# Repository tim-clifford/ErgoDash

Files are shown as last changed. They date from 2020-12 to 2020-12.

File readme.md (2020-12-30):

# ErgoDash-R

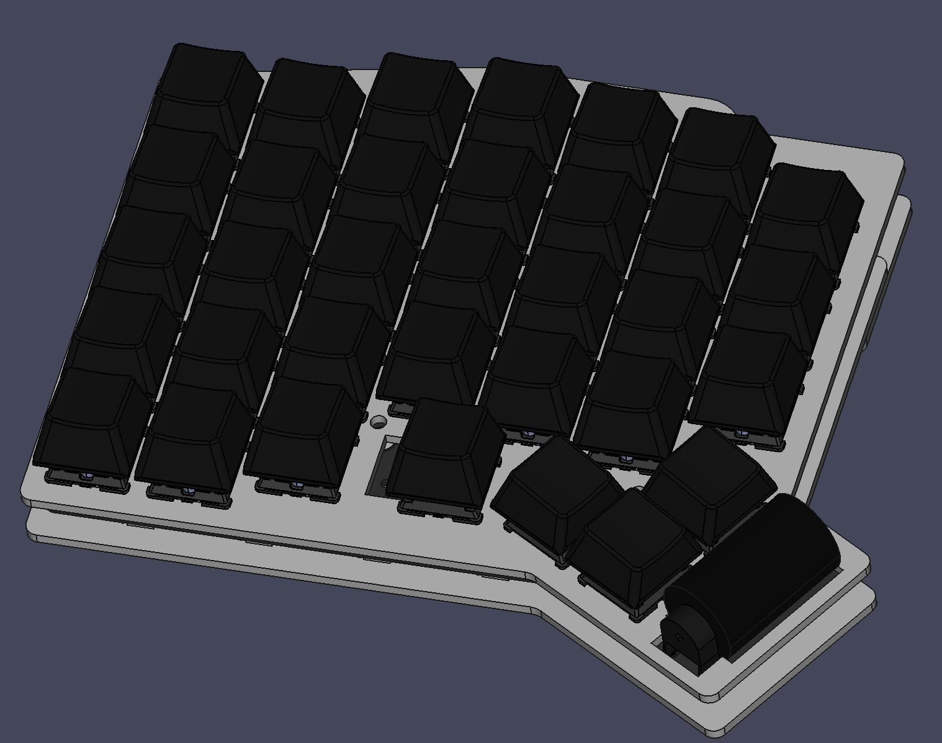
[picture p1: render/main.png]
ErgoDash-R


# Changes from original ErgoDash

- Added rotary encoder (scroll wheel) in place of the ErgoDash's optional outer thumb buttons
- Removed speaker to make pin available for rotary encoder
- Replaced firmware backlight control with physical toggle switch to make pin available for rotary encoder
- Replaced some parts with ones easier to obtain in the UK
- Added jumper pin positions for backlight switch and spare keyboard switch to allow adding functionality later

# Parts

[Parts List](https://github.com/tim-clifford/ErgoDash-R/tree/master/doc/shoplist.ods)

# Firmware

The ErgoDash-R uses QMK for its firmware. It will need updating from the original ErgoDash firmware here:
[QMK - ErgoDash directory](https://github.com/qmk/qmk_firmware/tree/master/keyboards/ergodash)
.  

# Build Guide

I will add a build guide once I have finished building mine! The original ErgoDash build guide is likely to be useful:

[ErgoDash Build Guide](https://github.com/omkbd/ErgoDash/blob/master/Doc/build-en.md)

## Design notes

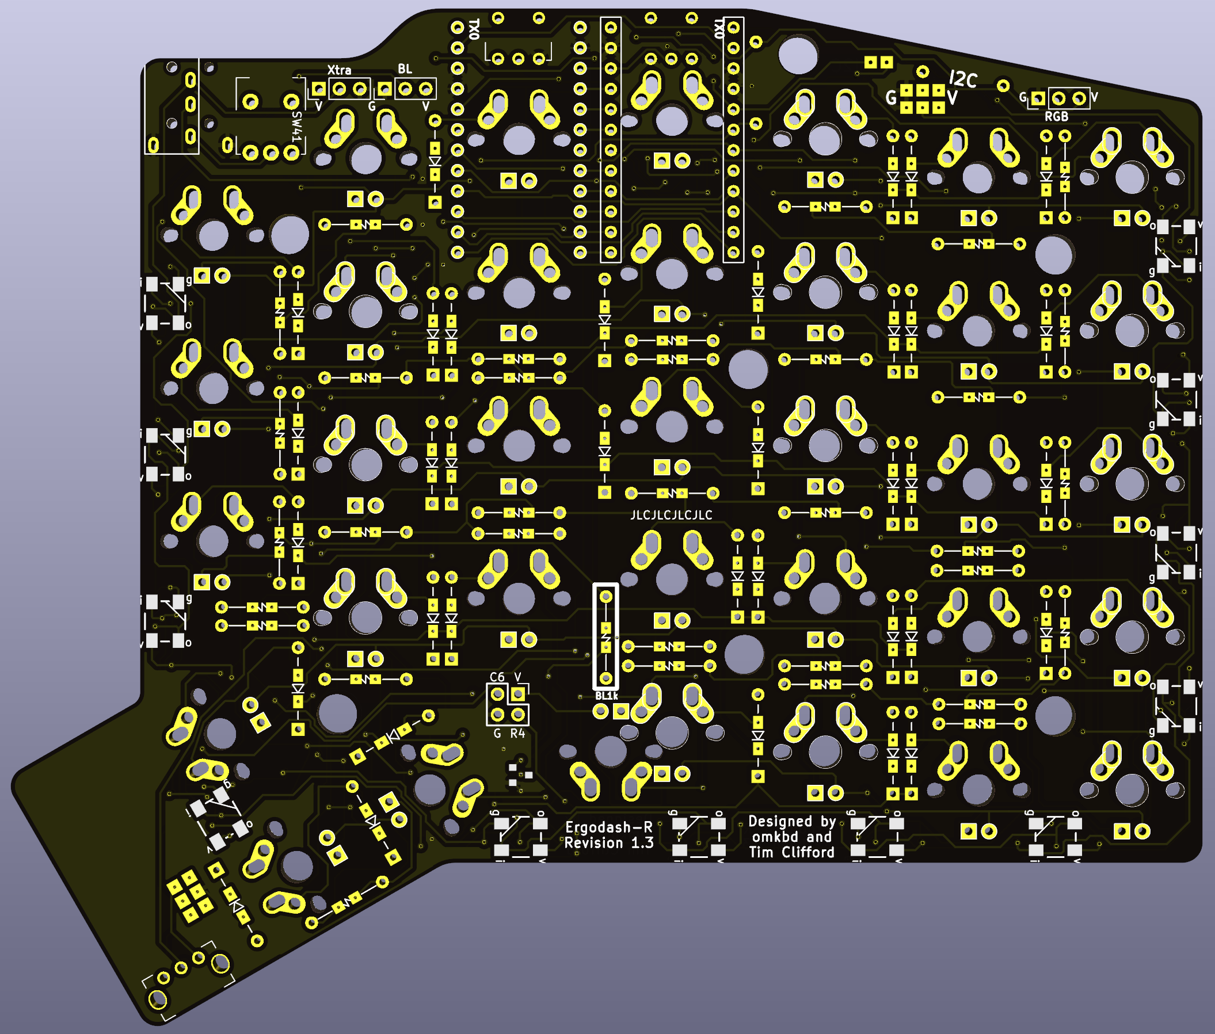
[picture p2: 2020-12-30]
render/pcb-bottom.png

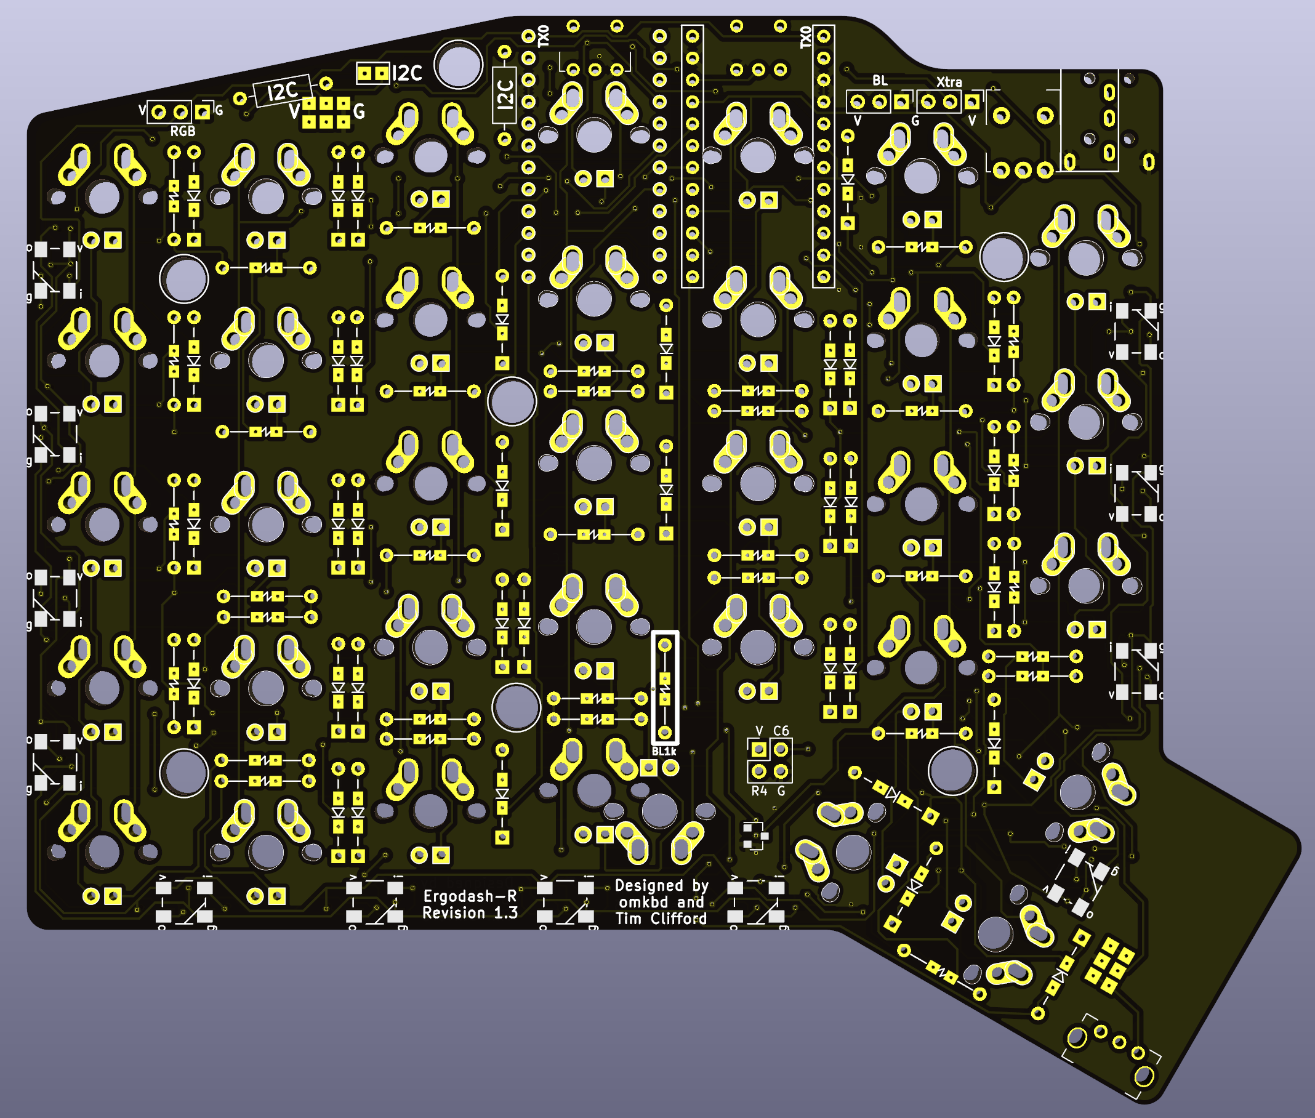
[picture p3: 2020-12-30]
render/pcb-top.png

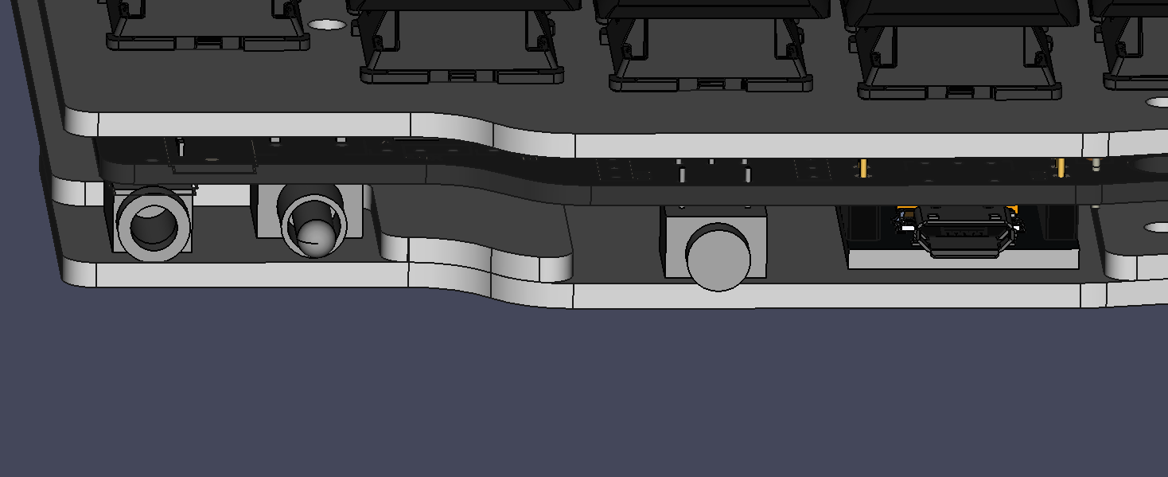
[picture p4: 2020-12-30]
render/io.png

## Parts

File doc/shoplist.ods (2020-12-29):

component | part number | quantity | lead time | pack | price | spares | spares value |  | link
Electronics
PCB | ErgoDash-R Rev 1.3 | 2 | 9-11 business | 5 | £15.74 | 3 | £9.44 | £9.44 | jlpcb.com + gerber files
switches | Cherry MX (Brown) | 68 | 0 | 70 | **£40.00 | 2 |  |  | https://www.ukkeycaps.co.uk/product/cherry-mx-switches
cheap switches | Gateron Blue | 68 | * | 70 | *£21.99 | 2 |  | £0.63 | https://www.ebay.co.uk/itm/70PCS-Pack-3Pin-Gateron-Clicky-Blue-Switch-Keyboard-Switch-for-Mechanical/264980422886
keycaps | Fully custom printed | 68 | * | 105 | **£44.38 | 37 |  |  | https://www.wasdkeyboards.com/104-key-custom-cherry-mx-keycap-set.html
cheap keycaps | QWERTY non backlit | 68 | * | 104 | *£9.90 | 36 |  | £3.43 | https://www.ebay.co.uk/itm/104-OEM-PBT-Double-Shot-Keycaps-Set-Backlit-for-Cherry-MX-Mechanical-Keyboards/203161540282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
diodes | 1N4148 | 70 | 1 | 100 | £1.06 | 30 | £0.32 | £0.32 | https://cpc.farnell.com/unbranded/1n4148/diode-high-speed-do-35-50pk/dp/SC07296
microcontroller | Pro Micro | 2 | 7 | 2 | £11.90 |  |  |  | https://www.ebay.co.uk/itm/Arduino-Pro-Micro-Leonardo-compatible-5V-16MHz-ATmega32U4-headers-UK-TESTED/251960157859
TRRS jack | PJ-320A | 2 | 16-36 | 10 | £2.53 | 8 | £2.02 | £2.02 | https://www.ebay.co.uk/itm/3-5-mm-Audio-Jack-Connector-PCB-Mount-Female-Socket-4-Pin-PJ-320A-10pcs/362585545084
reset switch | P8US8WR2C2M6RES | 2 | 20 | 2 | £3.16
pin header |  | 48 | * | 0
 |  |  |  |  | Total
 |  |  |  | 1st | £34.39 | £66.28 | £11.79 | £15.84
Case |  |  |  | 2nd | £16.12 | £48.01
case |  | 2 | 2 | 2 | £43.14 |  |  |  | razorlab.online + svg files
m2x5 |  | 22
m2x8 |  | 6
m2x6 spacer |  | 14
rubber feet |  | 8
 |  |  |  |  | Total
 |  |  |  | 1st | £43.14 | £43.14 | £0.00 | £0.00
Cables |  |  |  | 2nd | £43.14 | £43.14
TRRS cable |  | 1 | * | 1 | £2.65 |  |  |  | https://www.ebay.co.uk/itm/1m-Slim-4-Pin-3-5mm-Headphone-Aux-Audio-Mic-4-Pole-Stereo-Phone-Cable-1-metre/362051814231
micro-usb cable |  | 1 | * | 1 | £3.00
 |  |  |  |  | Total
 |  |  |  | 1st | £5.65 | £5.65 | £0.00 | £0.00
Scroll |  |  |  | 2nd | £5.65 | £5.65
rotary encoder | (Kailh Red) 9mm | 2 | 30-50 | 5 | £2.61 | 3 | £1.57 | £1.57 | https://www.ebay.co.uk/itm/5Pcs-Kailh-Edition-Mouse-Encoder-Highly-Accurate-Mouse-Decoder-Red-Core/293063741060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
knob | 28x17mm LxD | 2 | 3 | 2 | £12.78 |  |  |  | https://ironmongeryexperts.co.uk/matt-black-17mm-dia-knurled-cupboard-knob.html
grub screw | M4 – 2mm allen | 2 |  | 5 | £2.99 | 3 | £1.79 | £1.79 | https://www.ebay.co.uk/itm/M2-M2-5-M3-M4-M5-ALLEN-KEY-GRUB-SCREWS-CUP-POINT-SCREWS-A2-STAINLESS-DIN-916/383694660868
shaft | 1.74mm – 2mm allen | 2 | * | 0
 |  |  |  |  | Total
 |  |  |  | 1st | £18.38 | £18.38 | £3.36 | £3.36
Backlight |  |  |  | 2nd | £12.78 | £12.78
LEDs | 3mm purple | 68 | 5 | 100 | £4.95 | 32 | £1.58 | £1.58 | https://www.ebay.co.uk/itm/3mm-5mm-10mm-Ultra-Bright-Round-Water-Clear-LED-Bulb-3V-Light-Emitting-Diode/391733543929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
LED resistors | 470 maybe | 68 | 7 | 100 | £1.50 | 32 | £0.48 | £0.48 | https://www.ebay.co.uk/itm/272109823572?var=570918702940
signal resistors | 1k | 2 | 1 | 10 | £0.36 | 8 | £0.29 | £0.29 | https://cpc.farnell.com/multicomp-pro/mcmf006ff1001a50/res-1k-1-600mw-axial-metal-film/dp/RE07777
MOSFETs | IRLML6344TRPBF | 2 | 13 | 8 | £4.01 | 6 | £3.01 | £3.01 | https://www.ebay.co.uk/itm/193406202200
switch | MC2MS1T2B2M6RE | 2 | 1 | 2 | £2.26 |  |  |  | https://cpc.farnell.com/multicomp/mc2ms1t2b2m6re/switch-pcb-spdt-horiz/dp/SW02456?ost=mc2ms1t2b2m6re
 |  |  |  |  | Total
 |  |  |  |  | £13.08 | £13.08 | £5.36 | £5.36
Underglow |  |  |  |  | £8.71 | £8.71
LEDs or LED tape | WS2812B | 24 |  | 100 | £24.86 | 76 | £18.89 | £18.89 | https://www.amazon.co.uk/WS2812B-LED-5050-Controller-WS2811/dp/B00KFOLQ5O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
 |  |  |  |  | Total
 |  |  |  |  | £24.86 | £24.86 | £18.89 | £18.89
 |  |  |  |  | £0.00 | £0.00
CPC delivery total |  |  |  |  | £5.99 | £5.99
 |  | Core electronics |  |  | +Scroll wheels |  | +Per-key backlight |  | +Case |  | +RGB underglow & cables
 | 1st | £34.39 |  | £66.28 | £52.77 | £84.66 | £65.85 | £97.74 | £108.99 | £140.88 | £145.49 | £177.38
 | 2nd | £16.12 |  | £48.01 | £28.90 | £60.79 | £37.61 | £69.50 | £80.75 | £112.64 | £92.39 | £124.28
 |  | With no keyswitches or keycaps
 |  | With Gateron blues and stock ANSI keycaps

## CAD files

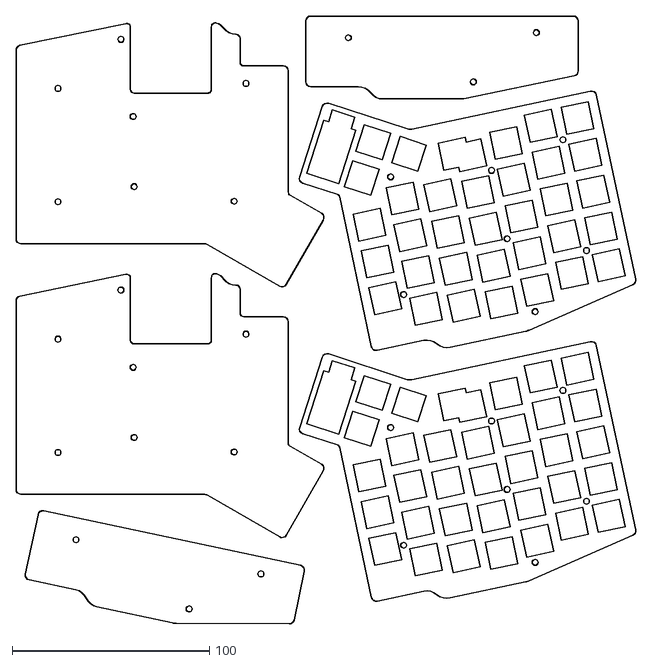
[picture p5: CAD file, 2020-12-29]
case/ErgoDash_Case.dxf
314.1 x 308.0

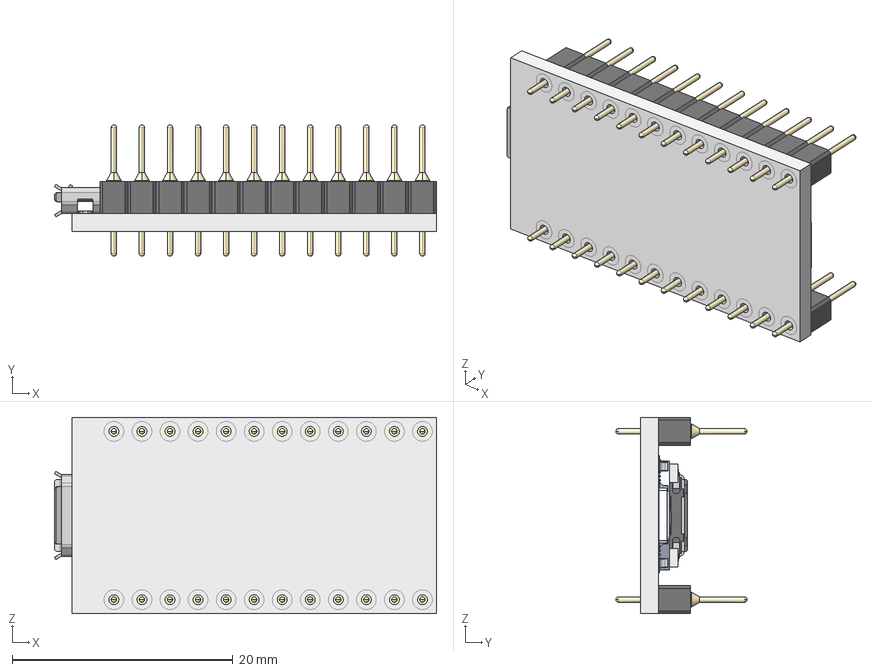
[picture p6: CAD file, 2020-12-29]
MCAD/parts-fcstd/ProMicro16MHz.FCStd
34.6 x 11.9 x 17.8 mm
MICRO_stackable header 12 x 2
MICRO_stackable header pin x 24
micro usb shell
micro usb internal
micro usb contact x 5
atmega32U4
MICRO_cap106C x 2
micro_crystal 5x3
micro_MIC5219
MICRO_PTC-1206
MICRO_603 cap on pad x 7
SOD 323
micro board

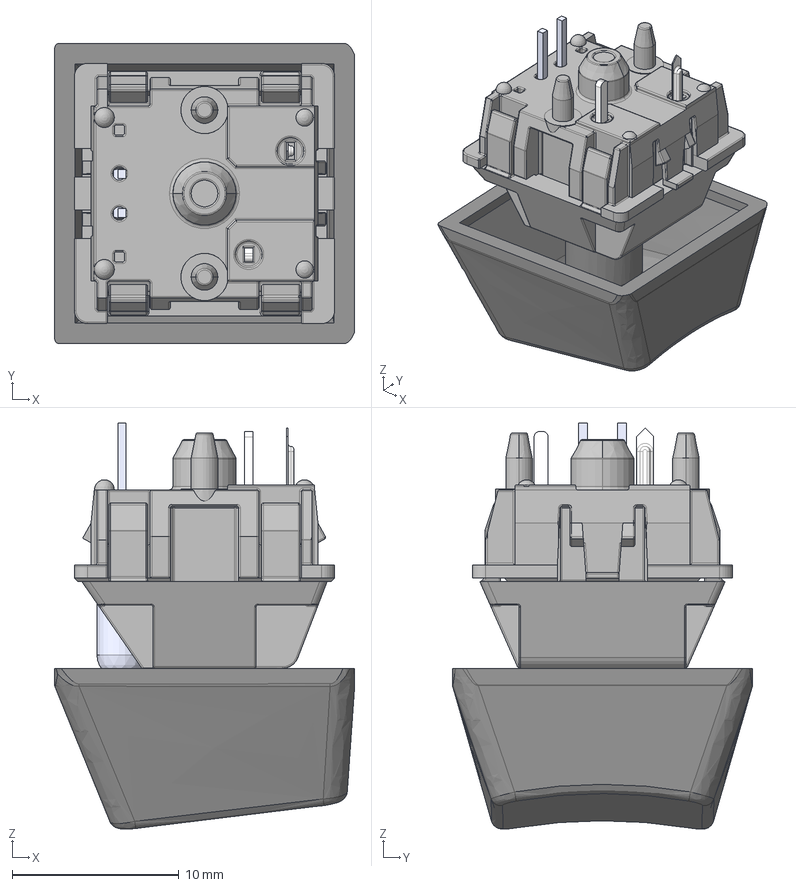
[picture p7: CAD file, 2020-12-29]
MCAD/parts-step/Cherry_MX_Switch_and_Keycap.step
18.0 x 18.0 x 24.3 mm
MX_轴_按键′_ü___¨1 x 2
MX_?_??ｨ｢ｨｬ_｡ｧ｡?__ x 2
MX?_?EDLEDLED x 2
MXﾖ畧ﾖ睥蘋ｵﾗｲｿ_ｦﾌ｡ﾁ2__ﾄｬﾈﾏ_ｨ｢2____ｨｨ_ x 2
?ｽ?__??__ｨｨ_ x 2
Cherry_MX_Keycap x 2

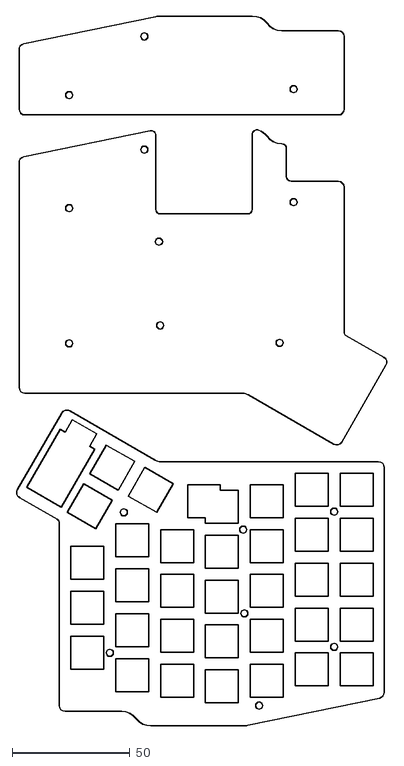
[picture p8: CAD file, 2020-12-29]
case/ErgoDash_Case_Half.dxf
157.5 x 301.4

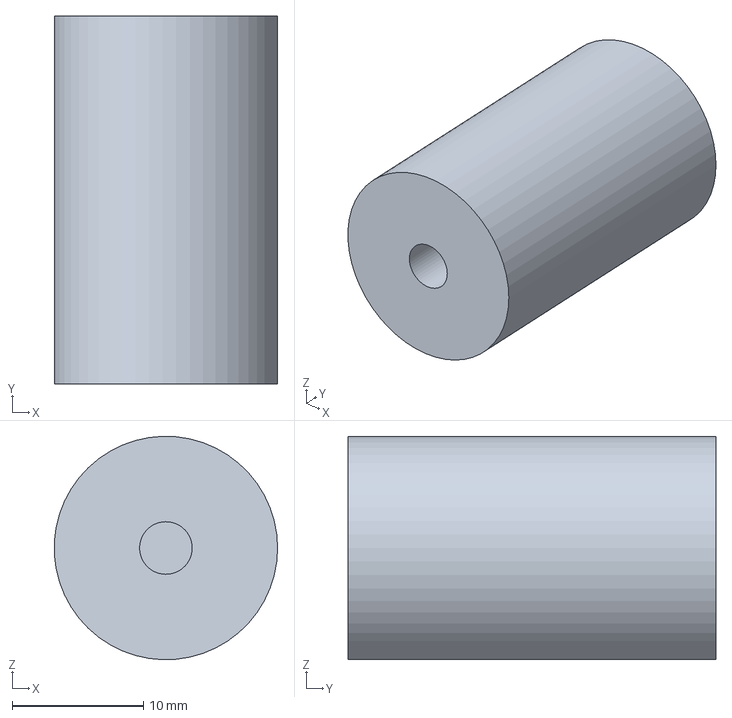
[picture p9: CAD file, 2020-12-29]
MCAD/parts-fcstd/Encoder_Knob.FCStd
17.0 x 28.0 x 17.0 mm

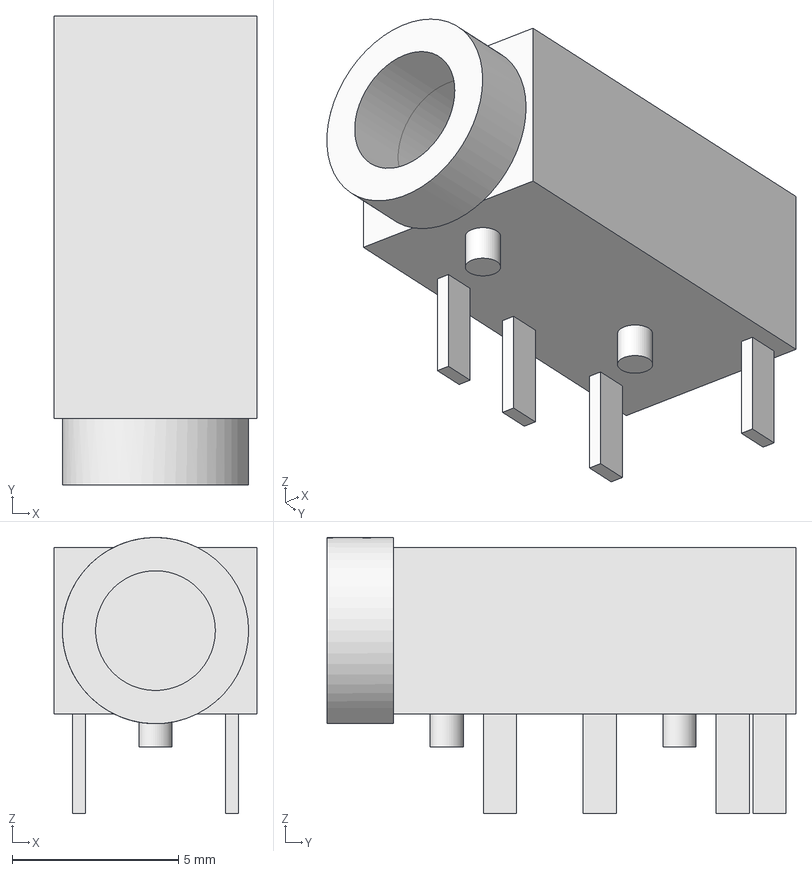
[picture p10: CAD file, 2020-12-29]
MCAD/parts-step/PJ320A_trrs_jack.step
6.10 x 14.1 x 8.30 mm

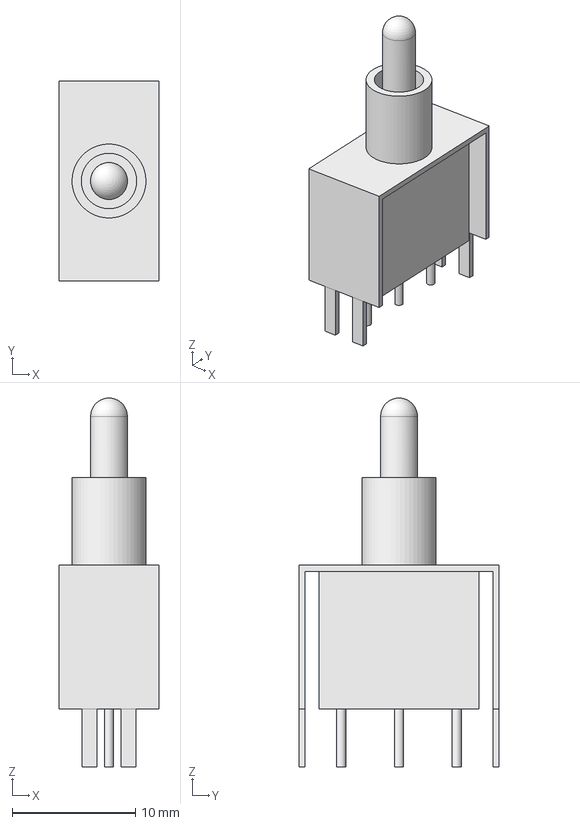
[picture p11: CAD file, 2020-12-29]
MCAD/parts-step/1MS1T2B4VS2RES_SPDT_Toggle_Switch.step
8.13 x 16.3 x 30.0 mm

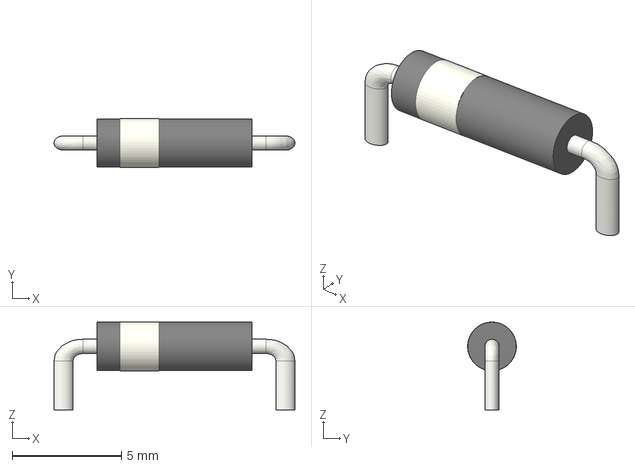
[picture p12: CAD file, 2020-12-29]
MCAD/parts-step/1N4148.step
11.0 x 2.23 x 4.03 mm

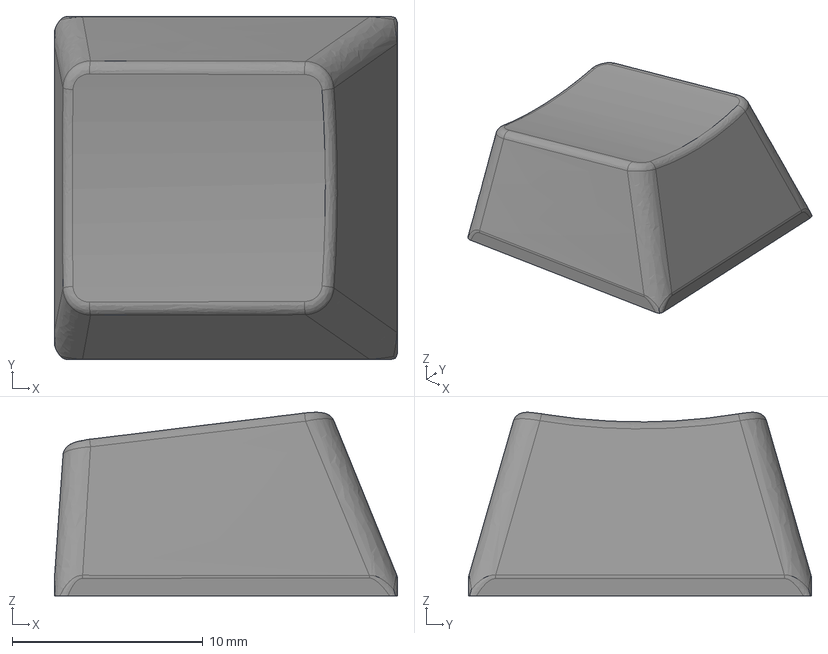
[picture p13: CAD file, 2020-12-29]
MCAD/parts-step/Cherry_MX_Keycap.step
18.0 x 18.0 x 9.64 mm

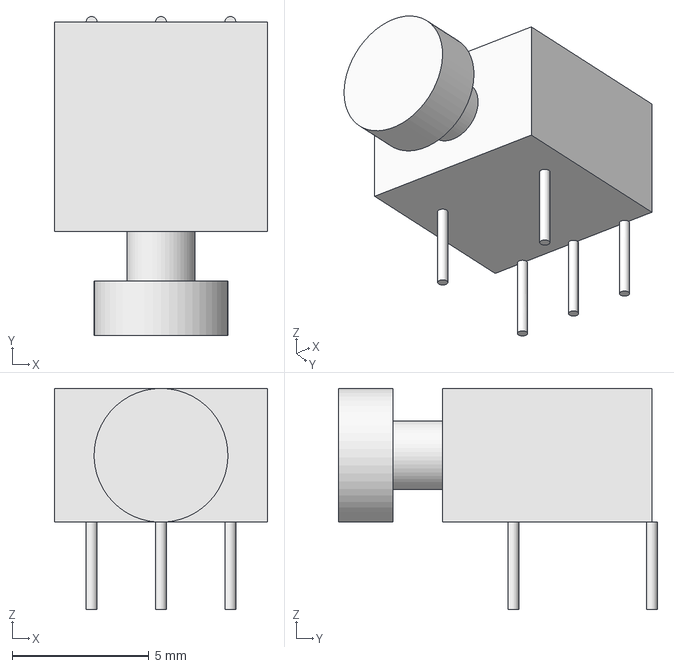
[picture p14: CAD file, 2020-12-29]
MCAD/parts-step/P8US8WR2C2M6RES_Push_Button.step
7.80 x 11.7 x 8.10 mm

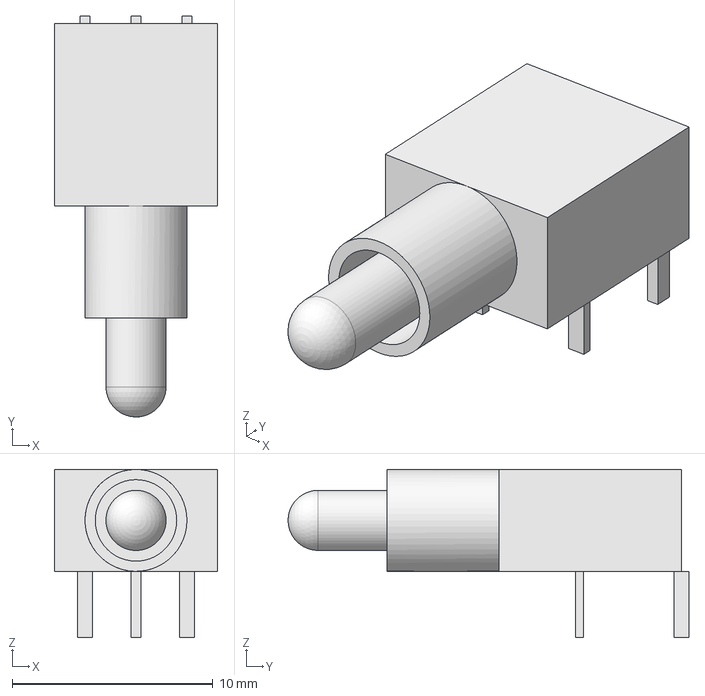
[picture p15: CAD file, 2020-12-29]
MCAD/parts-step/MC2MS1T2B2M6RE_SPDT_Toggle_Switch_Horizontal.step
8.13 x 20.0 x 8.38 mm

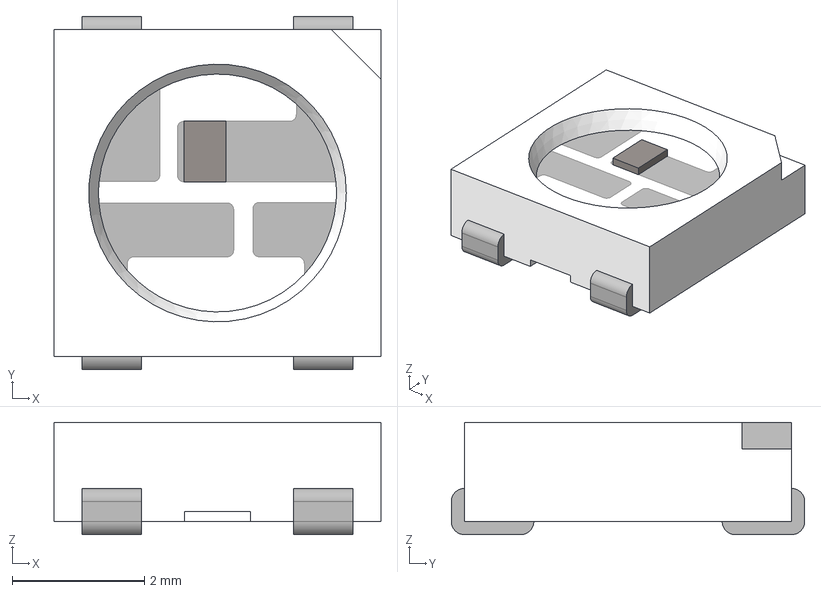
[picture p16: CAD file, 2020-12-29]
MCAD/parts-step/WS2812_RGB_LED.step
4.95 x 5.35 x 1.70 mm

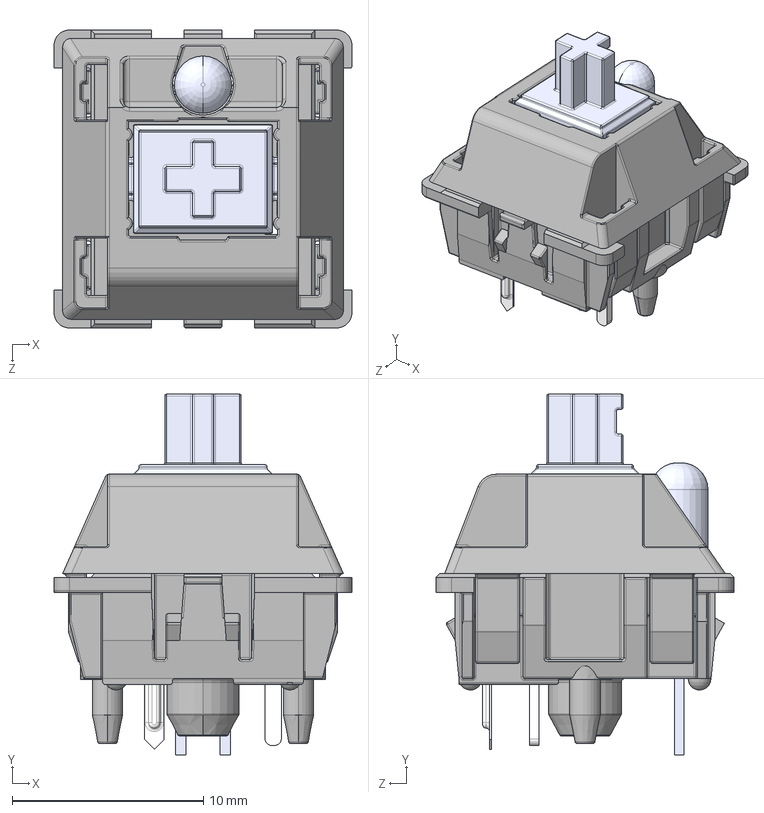
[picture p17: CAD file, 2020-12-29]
MCAD/parts-step/Cherry_MX_Switch.step
15.6 x 18.9 x 15.6 mm
MX 轴 按键′_ü___¨1
MX 轴 轴体áì_¨￠¨__
MX粣 拸簽LEDLEDLED
MX轴 轴体 底部 μ×2__默认_á2____è_
针脚___默认__è_

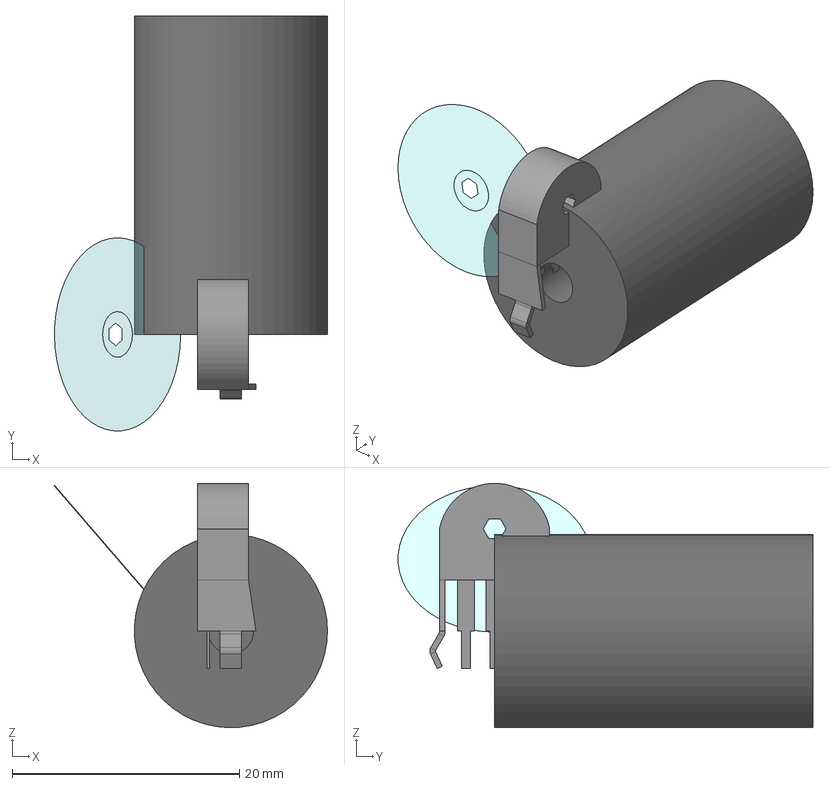
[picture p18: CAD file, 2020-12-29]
MCAD/parts-fcstd/CEN979012RO2_Kailh_Red_Encoder_9mm_with_Knob.FCStd
24.0 x 36.5 x 21.5 mm
CEN979012RO2_Kailh_Red_Encoder_9mm
Knob
_Element
_Element001

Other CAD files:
MCAD/parts-step/Cherry_MX_Switch_and_Keycap180.step
MCAD/parts-step/CEN979012RO2_Kailh_Red_Encoder_9mm.step
MCAD/ergodash-B_Silkscreen.dxf
MCAD/ergodash-F_Silkscreen.dxf
MCAD/parts-fcstd/1MS1T2B4VS2RES_SPDT_Toggle_Switch.FCStd
MCAD/parts-fcstd/CEN979012RO2_Kailh_Red_Encoder_9mm.FCStd
MCAD/parts-fcstd/Cherry_MX_Switch_and_Keycap.FCStd
MCAD/parts-fcstd/Cherry_MX_Switch_and_Keycap180.FCStd
MCAD/parts-fcstd/MC2MS1T2B2M6RE_SPDT_Toggle_Switch_Horizontal.FCStd
MCAD/parts-fcstd/P8US8WR2C2M6RES_Push_Button.FCStd
MCAD/parts-fcstd/PJ320A_trrs_jack.FCStd

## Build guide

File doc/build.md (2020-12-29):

# Notice

This is the build guide for the original ErgoDash, there are some differences for the ErgoDash-R! I will get around to rewriting this eventually.

# ErgoDash Build Guide
**Feel free not to read completely, but pay attention when installing the Pro Micro!!!!!!**
Note: The below diagrams are for rev 1.1. For rev 1.2. and up, the part placement is slightly different.

Translated, with extra build notes (From: build.md https://github.com/omkbd/ErgoDash/commit/d12e8f7fd414fe89d38b77b3b0e6a0af4b639a47)

## Overview
assembly

## 0 Preparation
Remove extra thumb key section if desired.
PCBcut
carefully break by hand

**Note:
Components in steps 3-6 and 10 must be inserted on the bottom of the board.
Components in steps 1 and 2 can be installed on the top or bottom.**

## 1 Install Diodes
When installing diodes the black stripe is towards the square pad
(diodes are all 1 square 1 round pad)
(resistors are all both round pad)
diode

Note the positions of diodes and resistors to avoid mistakes
diode

**Rev 1.2 positions are changed as below.**
diode

## 2 Backlight LED [optional]
Install the MOSFET (Install note/suggestion: pre-soldering the single pad worked well)
Install 1kΩ resistor in silk rectangle as noted 。(Silk screen notation is improved on rev 1.2 [BL1k])
1k

Install 470Ω resistors


-Note: Photo has a few surface mount resistors combined with through-hole
**(Rev 1.1) For the resistor found under the pro-micro: a surface mount resistor, or installing resistor on opposite side may be preferred to prevent interference (moved in rev 1.2)**

## 3 TRRS Jack
On the underside of the board, install the TRRS Jack as indicated by the silkscreen.

## 4 Install reset switch
The reset switch needs to go the underside of the board.
At the top of the board there are 2 locations for the pro-micro.
Pro Micro will be installed where the rectangular outline is printed
Reset switch is installed where the rectangular outline is not seen
Compare with photo on Step 6

## 5 Underglow LED [optional]
**The latest firmware is as follows.**  
There is no need to decide on a master.  
Jump from the back as follows.  
jump2  
Attach the LED chip so that the cut on both sides matches the silk.

**The firmware before 2019/5/5 is implemented as follows.**  
~~Choose which of the pair (left or right) will be master (where the USB cable will be attached), and solder the jumpers as below.~~  
~~The board in the photo below has the jumpers soldered for left hand master. The left hand board is on the right, and the right hand board is on the left.~~  
~~In the two diagrams, the upper image is for left hand master (labelled 左マスター), and the lower image is for right hand master (右マスター).~~  
jump

~~Install LED WS2812B~~  
~~**IMPORTANT**~~  
~~-On Master half, LED corner will Match the silkscreen~~  
~~-On Slave half, LED corner needs to be 180 from silkscreen~~  

-Installation notes:
  -use tape to hold in place, solder one side, remove tape, then solder other
  -Notes from first time soldering with these LED:
    -I attempted to pre-solder pads with bad results (As recommended for other surface mount I did before)
    -Leaving iron on too long appeared to melt the casing of the LED (Use fine tip if you have it? I didnt)
    -1sec on pad to pre-heat, then off and come back with iron and solder is what worked best for me

RGB_Left
RGB_Left_Finish

## 6 Pro Micro header  and reset switch installation
On the underside, attach Headers where you see the rectangular outline on silkscrean  (It is in the correct position on each side of the board)
**Do Not attach Pro Micro Yet**
When using spring headers, soldering the header to the board is unnecessary.

pin

## 7 Install Stabilizer （rev 1.2 or Later only）[optional]

(I used Rev 1.1 without Stabilizers, translation below)

If you will be using 2U keycap(s), then attach the stablizer(s). (If necessary; it's not always required).
**Note: Once the switch is installed, it's no longer possible to attach the stabilizer.**
Put together and attach as shown below.
assembly
If you're concerned about the noise of the stabilizer then apply grease (not included in kit).

## 8 Install Switches and Plate
Make sure all other components are installed before adding switches.
Place the plate with keyholes over top the PCB and snap in and solder switches.
Start with 4 corners in the plate to ensure alignment.
After the first 4 are soldered in, install remaining switches.
Just above the "ergoDash Rev 1.2" sign, there is two possible locations for the switch.
The recommanded location is at the right side for the right part of the keybord (to use it as arrow keys).
And at the left side for the left part of the keyboard (as a modifier)
See this picture (https://raw.githubusercontent.com/omkbd/picture/master/Ergodash.jpg)

switch
switch_complete

## 9 Backlight LED Install [optional]
Install the LEDs from the top on each switch
Round Pad  anode（＋）(Long LED Leg)
Square Pad  cathode（-) (Short Leg)
-Can be installed later (Except for the LED under pro-micro)

## 10 Pro Micro Install
**Before proceding connect the Pro Micro to a PC via USB and confirm it's working.**
-Confirm the TX0 lines up (USB port sandwiched between both PCBs)
-Check that all solder connections underneath the Pro Micro are done.
-Confirm no contact between Pro Micro and components (add insulating tape if desired)
-For spring headers, solder is required on the Pro Micro side.
-After installation, confirm the Pro Micro is properly seated. If not, cut the legs of the switch under the Pro Micro slightly.
-Trim headers after testing.

## 11 Case Assembly
Install the 5mm screws and 6mm spacers from the top。

spacer

Install 5mm and 8mm screws according to the diagram。

case

Install Rubber feet

gom

## 12 Firmware

QMK Build Guide
https://docs.qmk.fm/#/getting_started_build_tools

ErgoDash Firmware
https://github.com/qmk/qmk_firmware/tree/master/keyboards/ergodash

If the right hand side is the master, you need to build the firmware by specifying `MASTER_RIGHT` in the config.h file in the key map of qmk.  
To turn on Backlight and Underglow, add the following to rules.mk in the keymap.  
`BACKLIGHT_ENABLE = yes`  
`RGBLIGHT_ENABLE = yes  `
As the default setting, Underglow LEDs turn on, but Backlight LEDs don't turn on. If you want to confirm whether Backlight LEDs work normally or not, press the `BL_TOGG` key (this key is assigned to `Lower + Raise + S` on the default key map).

**If you used firmware 5/5/2019 or earlier in step 5, comment out the following line in rev1 / config.h.**  
`#define RGBLIGHT_SPLIT`  
`#define RGBLED_SPLIT { 12, 12 } `

Attach the keycaps, and you're done!!!!!

finish

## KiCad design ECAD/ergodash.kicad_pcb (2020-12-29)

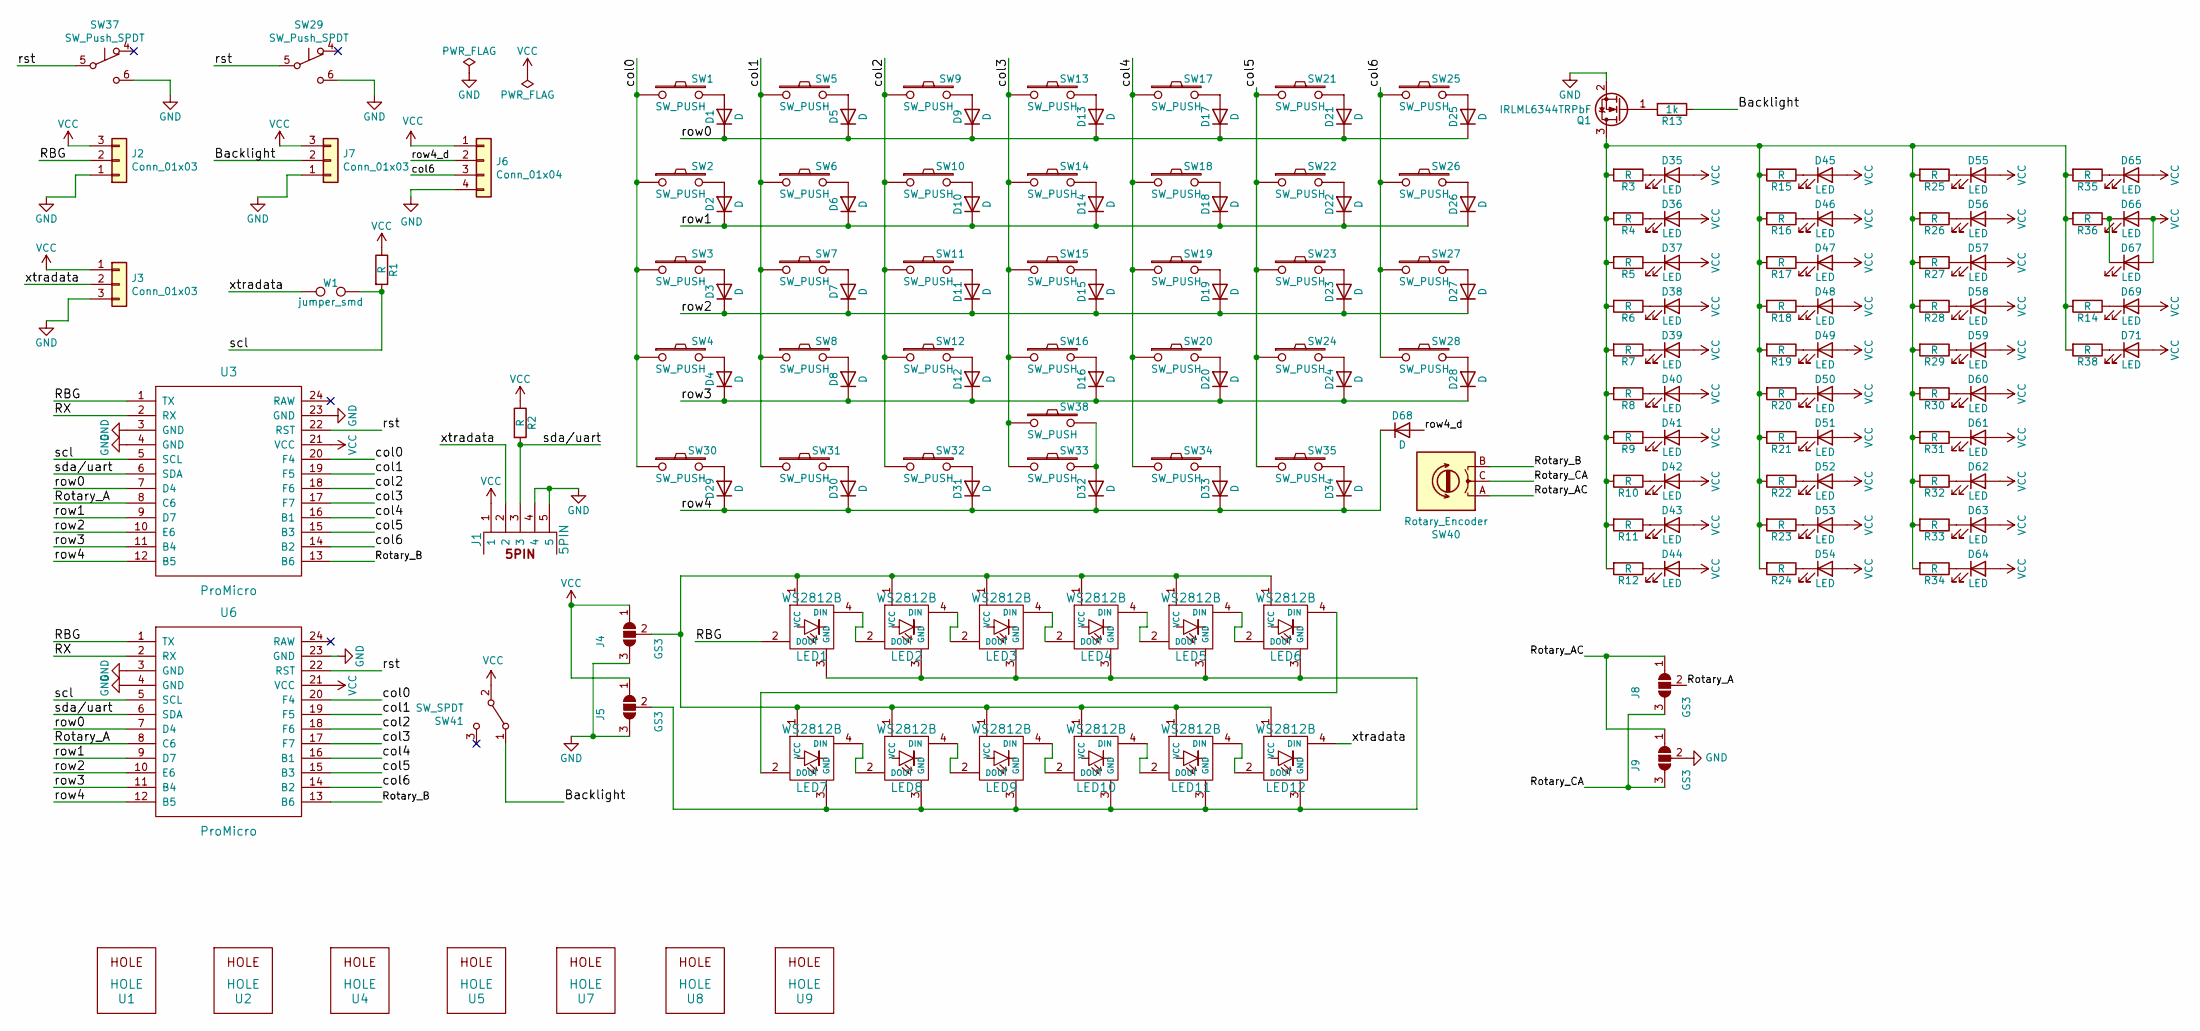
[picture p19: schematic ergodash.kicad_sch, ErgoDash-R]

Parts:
D1, D2, D3, D4, D5, D6, D7, D8, D9, D10, D11, D12, D13, D14, D15, D16, D17, D18, D19, D20, D21, D22, D23, D24, D25, D26, D27, D28, D29, D30, D31, D32, D33, D34, D68: D; Diode_SMD_THT3
D35, D36, D37, D38, D39, D40, D41, D42, D43, D44, D45, D46, D47, D48, D49, D50, D51, D52, D53, D54, D55, D56, D57, D58, D59, D60, D61, D62, D63, D64, D65, D66, D67, D69, D71: LED; CHERRY_MX_LED2
J1: 5PIN; trss_jack
J2, J3, J7: Conn_01x03; conn3
J4, J5, J8, J9: GS3; jumper2
J6: Conn_01x04; conn4
LED1, LED2, LED3, LED4, LED5, LED6, LED7, LED8, LED9, LED10, LED11, LED12: WS2812B; WS2812B-5
Q1: IRLML6344TRPbF; SOT-23_2
R1, R2: R; R_Axial_DIN0207_L6.3mm_D2.5mm_P10.16mm_Horizontal
R3, R4, R5, R6, R7, R8, R9, R10, R11, R12, R14, R15, R16, R17, R18, R19, R20, R21, R22, R23, R24, R25, R26, R27, R28, R29, R30, R31, R32, R33, R34, R35, R36, R38: R; Resistors_SMD_THT
R13: 1k; Resistors_SMD_THT
SW1, SW2, SW3, SW4, SW5, SW6, SW7, SW8, SW9, SW10, SW11, SW12, SW13, SW14, SW15, SW16, SW17, SW18, SW19, SW20, SW21, SW22, SW23, SW24, SW25, SW26, SW27, SW28, SW30, SW31, SW32, SW33, SW34, SW35, SW38: SW_PUSH; MX_ALPS
SW29, SW37: SW_Push_SPDT
SW40: Rotary_Encoder; Kailh_Encoder
SW41: SW_SPDT; MC2MS1T2B2M6RE
U1, U2, U4, U5, U7, U8, U9: HOLE; hole
U3, U6: ProMicro
W1: jumper_smd; jumper_smd_2dub

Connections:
/Backlight: J7.2, R13.1, SW41.1 (A)
/RBG: J2.2, LED1.2 (DOUT), U3.1 (TX), U6.1 (TX)
/RX: U3.2 (RX), U6.2 (RX)
/Rotary_A: J8.2 (C), U3.8 (C6), U6.8 (C6)
/Rotary_AC: J8.1 (A), J9.1 (A), SW40.A
/Rotary_B: SW40.B, U3.13 (B6), U6.13 (B6)
/Rotary_CA: J8.3 (B), J9.3 (B), SW40.C
/col0: SW1.1, SW2.1, SW3.1, SW4.1, SW30.1, U3.20 (F4), U6.20 (F4)
/col1: SW5.1, SW6.1, SW7.1, SW8.1, SW31.1, U3.19 (F5), U6.19 (F5)
/col2: SW9.1, SW10.1, SW11.1, SW12.1, SW32.1, U3.18 (F6), U6.18 (F6)
/col3: SW13.1, SW14.1, SW15.1, SW16.1, SW33.1, SW38.1, U3.17 (F7), U6.17 (F7)
/col4: SW17.1, SW18.1, SW19.1, SW20.1, SW34.1, U3.16 (B1), U6.16 (B1)
/col5: SW21.1, SW22.1, SW23.1, SW24.1, SW35.1, U3.15 (B3), U6.15 (B3)
/col6: J6.3, SW25.1, SW26.1, SW27.1, SW28.1, U3.14 (B2), U6.14 (B2)
/row0: D1.1 (K), D5.1 (K), D9.1 (K), D13.1 (K), D17.1 (K), D21.1 (K), D25.1 (K), U3.7 (D4), U6.7 (D4)
/row1: D2.1 (K), D6.1 (K), D10.1 (K), D14.1 (K), D18.1 (K), D22.1 (K), D26.1 (K), U3.9 (D7), U6.9 (D7)
/row2: D3.1 (K), D7.1 (K), D11.1 (K), D15.1 (K), D19.1 (K), D23.1 (K), D27.1 (K), U3.10 (E6), U6.10 (E6)
/row3: D4.1 (K), D8.1 (K), D12.1 (K), D16.1 (K), D20.1 (K), D24.1 (K), D28.1 (K), U3.11 (B4), U6.11 (B4)
/row4: D29.1 (K), D30.1 (K), D31.1 (K), D32.1 (K), D33.1 (K), D34.1 (K), D68.1 (K), U3.12 (B5), U6.12 (B5)
/row4_d: D68.2 (A), J6.2
/rst: SW29.5 (B), SW37.5 (B), U3.22 (RST), U6.22 (RST)
/scl: R1.2, U3.5 (SCL), U6.5 (SCL), W1.2
/sda/uart: J1.3, R2.2, U3.6 (SDA), U6.6 (SDA)
/xtradata: J1.2, J3.2, LED12.4 (DIN), W1.1
GND: J1.4, J1.5, J2.1, J3.3, J4.3 (B), J5.3 (B), J6.4, J7.1, J9.2 (C), Q1.2 (S), SW29.6 (C), SW37.6 (C), U3.3 (GND), U3.4 (GND), U3.23 (GND), U6.3 (GND), U6.4 (GND), U6.23 (GND)
unnamed: D1.2 (A), SW1.2
unnamed: D2.2 (A), SW2.2
unnamed: D3.2 (A), SW3.2
unnamed: D4.2 (A), SW4.2
unnamed: D5.2 (A), SW5.2
unnamed: D6.2 (A), SW6.2
unnamed: D7.2 (A), SW7.2
unnamed: D8.2 (A), SW8.2
unnamed: D9.2 (A), SW9.2
unnamed: D10.2 (A), SW10.2
unnamed: D11.2 (A), SW11.2
unnamed: D12.2 (A), SW12.2
unnamed: D13.2 (A), SW13.2
unnamed: D14.2 (A), SW14.2
unnamed: D15.2 (A), SW15.2
unnamed: D16.2 (A), SW16.2
unnamed: D17.2 (A), SW17.2
unnamed: D18.2 (A), SW18.2
unnamed: D19.2 (A), SW19.2
unnamed: D20.2 (A), SW20.2
unnamed: D21.2 (A), SW21.2
unnamed: D22.2 (A), SW22.2
unnamed: D23.2 (A), SW23.2
unnamed: D24.2 (A), SW24.2
unnamed: D25.2 (A), SW25.2
unnamed: D26.2 (A), SW26.2
unnamed: D27.2 (A), SW27.2
unnamed: D28.2 (A), SW28.2
unnamed: D29.2 (A), SW30.2
unnamed: D30.2 (A), SW31.2
unnamed: D31.2 (A), SW32.2
unnamed: D32.2 (A), SW33.2, SW38.2
unnamed: D33.2 (A), SW34.2
unnamed: D34.2 (A), SW35.2
unnamed: D35.1 (K), R3.1
unnamed: D36.1 (K), R4.1
unnamed: D37.1 (K), R5.1
unnamed: D38.1 (K), R6.1
unnamed: D39.1 (K), R7.1
unnamed: D40.1 (K), R8.1
unnamed: D41.1 (K), R9.1
unnamed: D42.1 (K), R10.1
unnamed: D43.1 (K), R11.1
unnamed: D44.1 (K), R12.1
unnamed: D45.1 (K), R15.1
unnamed: D46.1 (K), R16.1
unnamed: D47.1 (K), R17.1
unnamed: D48.1 (K), R18.1
unnamed: D49.1 (K), R19.1
unnamed: D50.1 (K), R20.1
unnamed: D51.1 (K), R21.1
unnamed: D52.1 (K), R22.1
unnamed: D53.1 (K), R23.1
unnamed: D54.1 (K), R24.1
unnamed: D55.1 (K), R25.1
unnamed: D56.1 (K), R26.1
unnamed: D57.1 (K), R27.1
unnamed: D58.1 (K), R28.1
unnamed: D59.1 (K), R29.1
unnamed: D60.1 (K), R30.1
unnamed: D61.1 (K), R31.1
unnamed: D62.1 (K), R32.1
unnamed: D63.1 (K), R33.1
unnamed: D64.1 (K), R34.1
unnamed: D65.1 (K), R35.1
unnamed: D66.1 (K), D67.1 (K), R36.1
unnamed: D69.1 (K), R14.1
unnamed: D71.1 (K), R38.1
unnamed: J4.2 (C), LED1.1 (VCC), LED2.1 (VCC), LED3.1 (VCC), LED4.1 (VCC), LED5.1 (VCC), LED6.1 (VCC), LED7.1 (VCC), LED8.1 (VCC), LED9.1 (VCC), LED10.1 (VCC), LED11.1 (VCC), LED12.1 (VCC)
unnamed: J5.2 (C), LED1.3 (GND), LED2.3 (GND), LED3.3 (GND), LED4.3 (GND), LED5.3 (GND), LED6.3 (GND), LED7.3 (GND), LED8.3 (GND), LED9.3 (GND), LED10.3 (GND), LED11.3 (GND), LED12.3 (GND)
unnamed: LED1.4 (DIN), LED2.2 (DOUT)
unnamed: LED2.4 (DIN), LED3.2 (DOUT)
unnamed: LED3.4 (DIN), LED4.2 (DOUT)
unnamed: LED4.4 (DIN), LED5.2 (DOUT)
unnamed: LED5.4 (DIN), LED6.2 (DOUT)
unnamed: LED6.4 (DIN), LED7.2 (DOUT)
unnamed: LED7.4 (DIN), LED8.2 (DOUT)
unnamed: LED8.4 (DIN), LED9.2 (DOUT)
unnamed: LED9.4 (DIN), LED10.2 (DOUT)
unnamed: LED10.4 (DIN), LED11.2 (DOUT)
unnamed: LED11.4 (DIN), LED12.2 (DOUT)
unnamed: Q1.1 (G), R13.2
unnamed: Q1.3 (D), R3.2, R4.2, R5.2, R6.2, R7.2, R8.2, R9.2, R10.2, R11.2, R12.2, R14.2, R15.2, R16.2, R17.2, R18.2, R19.2, R20.2, R21.2, R22.2, R23.2, R24.2, R25.2, R26.2, R27.2, R28.2, R29.2, R30.2, R31.2, R32.2, R33.2, R34.2, R35.2, R36.2, R38.2
VCC: D35.2 (A), D36.2 (A), D37.2 (A), D38.2 (A), D39.2 (A), D40.2 (A), D41.2 (A), D42.2 (A), D43.2 (A), D44.2 (A), D45.2 (A), D46.2 (A), D47.2 (A), D48.2 (A), D49.2 (A), D50.2 (A), D51.2 (A), D52.2 (A), D53.2 (A), D54.2 (A), D55.2 (A), D56.2 (A), D57.2 (A), D58.2 (A), D59.2 (A), D60.2 (A), D61.2 (A), D62.2 (A), D63.2 (A), D64.2 (A), D65.2 (A), D66.2 (A), D67.2 (A), D69.2 (A), D71.2 (A), J1.1, J2.3, J3.1, J4.1 (A), J5.1 (A), J6.1, J7.3, R1.1, R2.1, SW41.2 (B), U3.21 (VCC), U6.21 (VCC)
no_connect_110: SW29.4 (A)
no_connect_111: SW37.4 (A)
no_connect_112: SW41.3 (C)
no_connect_113: U3.24 (RAW)
no_connect_114: U6.24 (RAW)

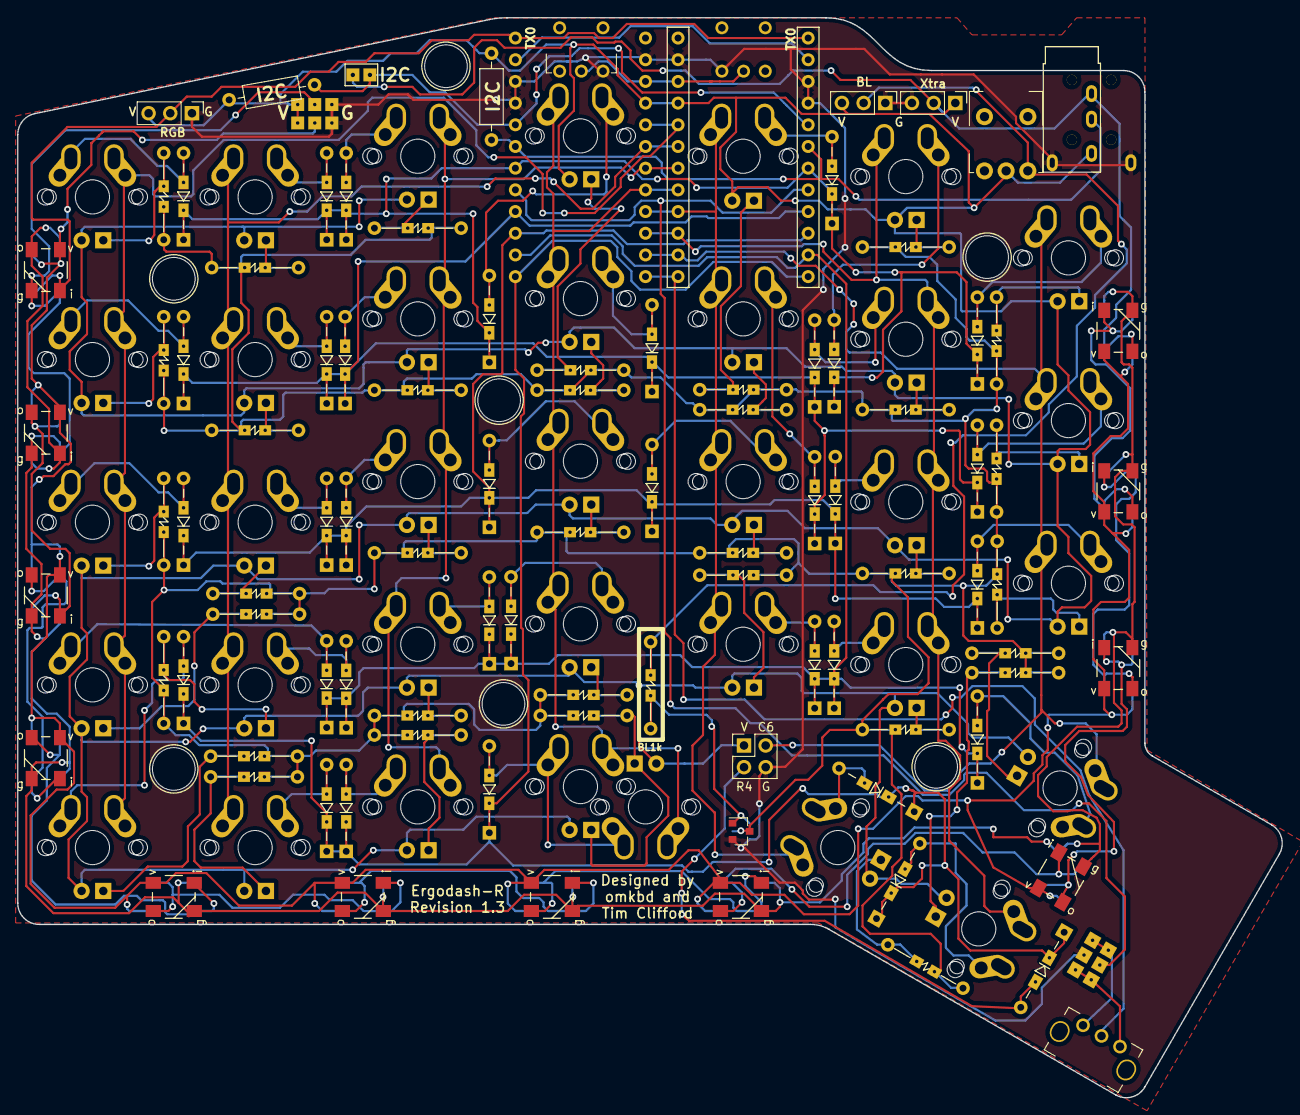
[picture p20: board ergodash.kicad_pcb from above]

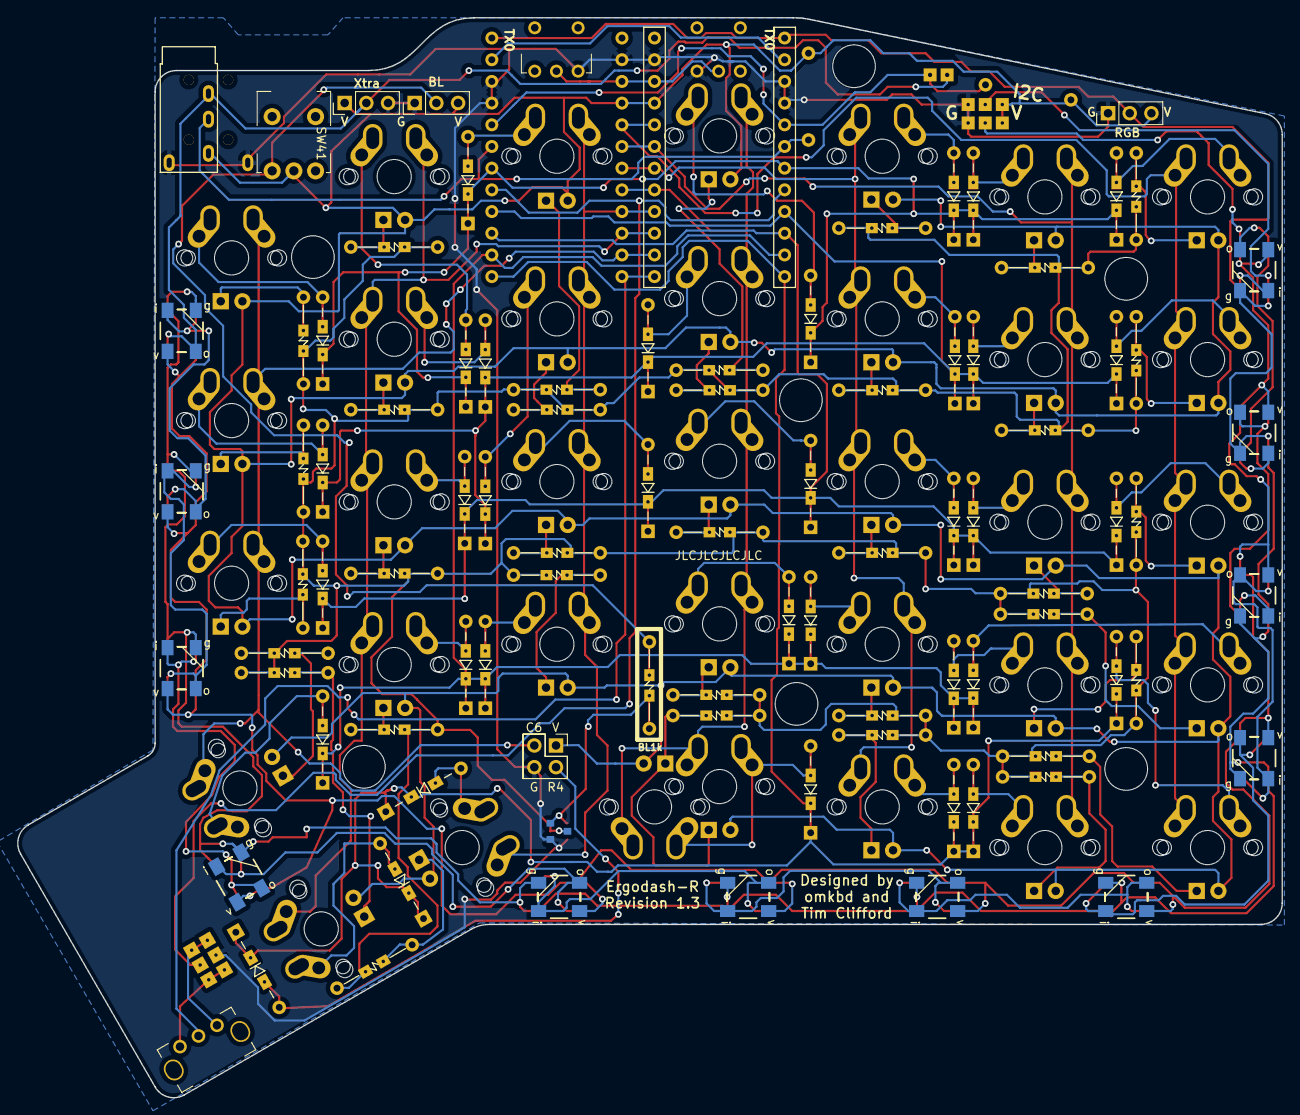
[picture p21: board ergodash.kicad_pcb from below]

Board: 2 copper layers, 148.1 x 126.5 mm, 178 parts (28 on the bottom side), 109 nets.

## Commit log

2020-12-17 Increase thickness of connection to optional thumb pads and update EESchema symbols
    [ergodash.kicad_pcb, ergodash.sch]
2020-12-17 Convert to Kicad 6
    [ergodash.kicad_pcb, ergodash.kicad_sch]
